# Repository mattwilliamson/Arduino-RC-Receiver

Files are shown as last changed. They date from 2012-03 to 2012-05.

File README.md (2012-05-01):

This is a simple project which will control a Radio Controlled vehicle via a serial interface, such as XBee or Bluetooth. The included `joystick.py` will use a joystick to transmit via XBee (or whatever serial interface you are using).

## Requirements:

* pyserial
* pygame

# TODO

**This project has been changed to send SUM PPM over Digital Pin 9 from the arduino to the aeroquad Digital 2 pin instead of one pin for each channel.** All of the diagrams below info pertains to the sketch names `serial_servo_rx`.

## Usage

* Upload the `serial_ppm_rx` sketch to your Arduino.
* Connect your servos to your Arduino per the below pinouts
* Run `python joystick.py`
* Use your joystick and watch the servos go!

I am using an XBee hooked up to an arduino plugged into my computer as the serial out interface and the other XBee is connected to my Arduino.

You can use whatever radio (including bluetooth) as long as your computer recognizes it as a serial port and the receiver spits out TTL on RX0 on your Arduino.

One example would be a standard bluetooth adapter on your computer and one of these [bluetooth ttl adapters](http://www.amazon.com/gp/product/B006T0Q8AQ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).

As for the joystick, I am using a [Saitek ST290](http://www.amazon.com/gp/product/B0000AW9RE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)
so you may need to change the code a little to match the buttons you want to perform which function.

Currently all buttons work as toggles.

## Caveats

* Set your XBees to 38400 baud. This was picked since it's safe to use with Series 1 XBee radios.

## Pinouts

This is as it relates to the `joystick.py` control file and it maps to the Saitek joystick mentioned above.

* Arduino Digital 2: Throttle
* Arduino Digital 3: Roll
* Arduino Digital 4: Pitch
* Arduino Digital 5: Yaw
* Arduino Digital 6: Aux1
* Arduino Digital 7: Aux2
* Arduino Digital 8: Aux3
* Arduino Digital 9: Aux4
* Arduino Digital 13: Status LED

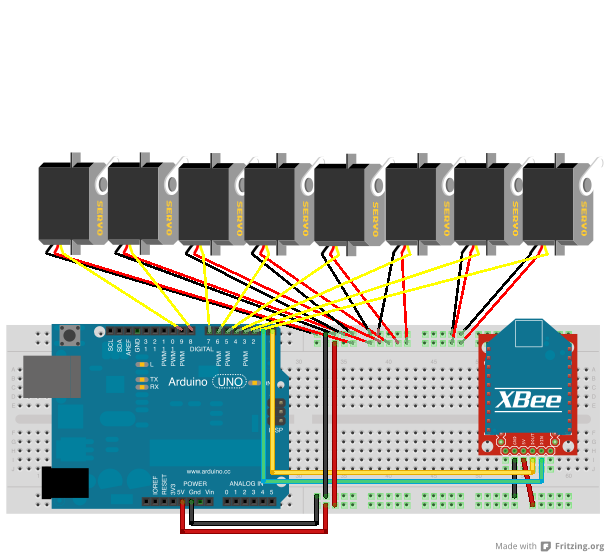
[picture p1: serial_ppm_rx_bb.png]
Schematic


Breadboard

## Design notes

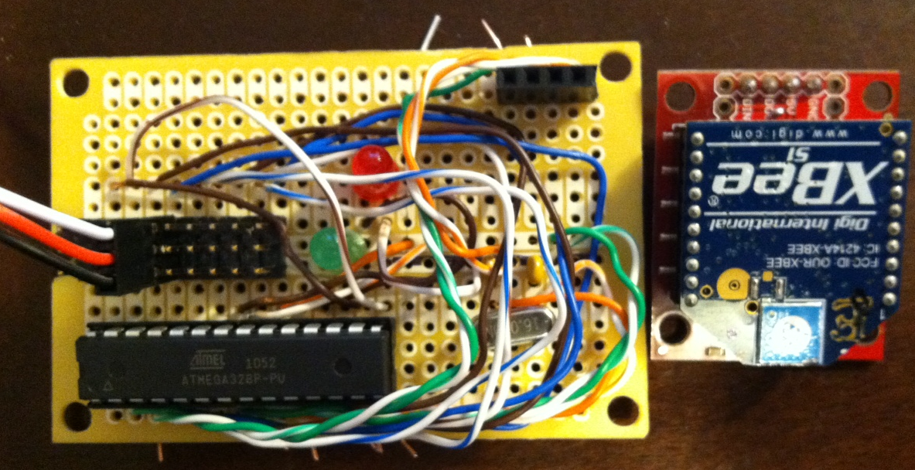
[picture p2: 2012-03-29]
receiver_board.png

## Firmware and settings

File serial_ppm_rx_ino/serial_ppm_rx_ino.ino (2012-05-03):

#include <TimerOne.h> 

#define CHANNELS 8

// Set these a little high since they are registering low on AQ
#define MIN_PULSE_TIME 1030   // 1000us
#define MAX_PULSE_TIME 1990   // 2000us
#define HALF_PULSE_TIME (MIN_PULSE_TIME + MAX_PULSE_TIME) / 2
#define SYNC_PULSE_TIME 3050  // 3000us

#define SERIAL_BAUD 38400

#define PIN_LED 13
#define PIN_PPM 9

#define RECEIVER_TIMEOUT 1500 // 1.5s
#define MIN_RECEIVER_VALUE 0
#define MAX_RECEIVER_VALUE 250

// For Aeroquad, this should disarm the quad when reception is lost
// TODO: Need to match AQ's channels
// YAXIS,ZAXIS,THROTTLE,XAXIS,AUX1,AUX2,0,0
const unsigned int defaultPulseWidths[CHANNELS] = {
  MIN_PULSE_TIME,      // Throttle
  HALF_PULSE_TIME,     // Roll
  HALF_PULSE_TIME,     // Pitch
  MIN_PULSE_TIME,      // Yaw
  
  MAX_PULSE_TIME,     // AUX1 (MODE in Aeroquad)
  MAX_PULSE_TIME,     // AUX2 (ALTITUDE in Aeroquad)
  MAX_PULSE_TIME,     // AUX3
  MAX_PULSE_TIME      // AUX4
};


// Inbound data is: [throttle, roll, pitch, yaw, aux1, aux2, aux3, aux4]
// AeroQuad expects: [XAXIS,YAXIS,THROTTLE,ZAXIS,MODE,AUX1,AUX2,AUX3]
// Make sure you define SERIAL_SUM_PPM_2 in AeroQuad!
const int channelMap[CHANNELS] = {1, 2, 0, 3, 4, 5, 6, 7};

unsigned int pulseWidths[CHANNELS];
byte buffer[CHANNELS];
int bytesReceived;
byte currentByte;
unsigned long lastReceived = 0;
boolean armed = false;

void setDefaultPulseWidths() {
  for (int i=0; i<CHANNELS; i++) {
    pulseWidths[i] = defaultPulseWidths[i];
  }
}

void setup() {
  pinMode(PIN_LED, OUTPUT);
  pinMode(PIN_PPM, OUTPUT);

  Serial.begin(38400);
  
  setDefaultPulseWidths();
  
  // Start timer with sync pulse
  Timer1.initialize(SYNC_PULSE_TIME);
  Timer1.attachInterrupt(isr_sendPulses);
  isr_sendPulses();
}

void loop() {
  handleSerial();
  checkArmed();
  checkLostReception();
} 

void handleSerial() {
  // Handle Serial Data
  if (Serial.available()) {
    lastReceived = millis();
    currentByte = Serial.read();

    if (currentByte == 254) {
      // Either packet is done, or we got corrupt data. Reset the packet
      bytesReceived = 0;
    } else {
      buffer[bytesReceived] = currentByte;
      bytesReceived++;
    }

    if (bytesReceived == CHANNELS) {
      bytesReceived = 0;
      armed = true;

      // Convert char (0-250) to pulse width (1000-2000)
      for (int i=0; i<CHANNELS; i++) {
        pulseWidths[i] = map(buffer[i], MIN_RECEIVER_VALUE, MAX_RECEIVER_VALUE, 
                                        MIN_PULSE_TIME, MAX_PULSE_TIME);
      }
    }
  }
}

void checkArmed() {
  if(!armed) {
    // Not Armed yet (no packets received) or lost reception, blink the LED
    // and set the dault positions
    setDefaultPulseWidths();
    
    digitalWrite(PIN_LED, HIGH);
    delay(300);
    
    digitalWrite(PIN_LED, LOW);
    delay(300);
  } else {
    digitalWrite(PIN_LED, HIGH);
  }
}

void checkLostReception() {
  // Check if we lost reception
  if(armed && lastReceived > 0 &&  millis() - lastReceived > RECEIVER_TIMEOUT) {
    armed = false;
    
    for(int i=0; i<5; i++) {
      digitalWrite(PIN_LED, HIGH);
      delay(100);
      digitalWrite(PIN_LED, LOW);
      delay(100);
    }
  }
}

// Sync pulse first
volatile int currentChannel = 0;

void isr_sendPulses() {
  digitalWrite(PIN_PPM, LOW);
  
  if (currentChannel == CHANNELS) {
    // After last channel
    Timer1.setPeriod(SYNC_PULSE_TIME);
    currentChannel = 0; // Will be 0 on next interrupt
  } else {
    Timer1.setPeriod(pulseWidths[channelMap[currentChannel]]);
    currentChannel++;
  }
  
  digitalWrite(PIN_PPM, HIGH);
}

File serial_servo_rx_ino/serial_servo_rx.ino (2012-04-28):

#include <Servo.h> 

#define SERVOS 8
#define PIN_LED 13
#define LED_TIME 1000
#define MIN_SERVO_POS 40
#define MAX_SERVO_POS 150
#define AUTO_DESCENT_ENABLED
#define AUTO_DESCENT_TIMEOUT 1500
#define AUTO_DESCENT_RATE 1 // Per 100ms

Servo servos[SERVOS];
int positions[SERVOS];
byte buffer[SERVOS];
int bytesReceived;
byte currentByte;
unsigned long lastReceived;
unsigned long lastLed;
boolean armed = false;

void setup() 
{ 
  pinMode(PIN_LED, OUTPUT); 
  Serial.begin(38400);
  bytesReceived = 0;
  lastReceived = 0;
  lastLed = 0;

  for(int i=0; i<SERVOS; i++) {
    positions[i] = MIN_SERVO_POS;
    servos[i].attach(1 + i);
    servos[i].write(MIN_SERVO_POS);
  }
} 


void loop() 
{
  if(lastLed && abs(millis() - lastReceived) > LED_TIME) {
    digitalWrite(PIN_LED, LOW);
    lastLed = 0;
  }

  if (Serial.available() > 0) {
    digitalWrite(PIN_LED, HIGH);
    lastReceived = millis();
    lastLed = lastReceived;
    currentByte = Serial.read();
    armed = true;

    if (currentByte == 254) {
      // Either packet is done, or we got corrupt data. Reset the packet
      bytesReceived = 0;
    }

    buffer[bytesReceived] = currentByte;
    bytesReceived++;

    if(bytesReceived == SERVOS) {
      bytesReceived = 0;

      // Send Servo Commands
      for(int i=0; i<SERVOS; i++) {
        int servoPos = map(buffer[i], 0, 250, MIN_SERVO_POS, MAX_SERVO_POS);
        servos[i].write(servoPos);
        positions[i] = servoPos;
      }
    }
  }

  if(!armed) {
    // Autodescent
#ifdef AUTO_DESCENT_ENABLED
    servos[2].write((MAX_SERVO_POS + MIN_SERVO_POS) / 2);
    positions[2] = (MAX_SERVO_POS + MIN_SERVO_POS) / 2;
    servos[3].write((MAX_SERVO_POS + MIN_SERVO_POS) / 2);
    positions[3] = (MAX_SERVO_POS + MIN_SERVO_POS) / 2;
    servos[4].write((MAX_SERVO_POS + MIN_SERVO_POS) / 2);
    positions[4] = (MAX_SERVO_POS + MIN_SERVO_POS) / 2;

    // Aux1
    servos[5].write(MAX_SERVO_POS);
    positions[5] = MAX_SERVO_POS;
#endif
    

    // Throttle
    int stepInterval = 100;

    while (positions[1] > MIN_SERVO_POS) {
      delay(stepInterval / 2);
      digitalWrite(PIN_LED, HIGH);

      positions[1] -= AUTO_DESCENT_RATE;
      positions[1] = positions[1] > MIN_SERVO_POS ? positions[1] : MIN_SERVO_POS;
      servos[1].write(positions[1]);

      delay(stepInterval / 2);
      digitalWrite(PIN_LED, LOW);
    }

    // Not Armed yet (no packets received), blink the LED
    digitalWrite(PIN_LED, HIGH);
    delay(500);
    digitalWrite(PIN_LED, LOW);
    delay(500);
  }

#ifdef AUTO_DESCENT_ENABLED
  unsigned long now = millis();

  if(lastReceived > 0 && lastReceived < now && (now - lastReceived) > AUTO_DESCENT_TIMEOUT) {
    armed = false;
  }
#endif
} 

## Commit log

2012-03-29 Added diagram
    [serial_ppm_rx.fzz]
2012-03-29 Added schematic to readme
2012-03-29 Updated schematic
    [serial_ppm_rx.fzz]
2012-03-29 Added actual board
2012-04-19 Transmitter works with quadcopter and even has autodescent in case of lost signal\!
    [nano_receiver.fzz]
2012-05-02 Added link to Arduino IDE
2012-05-02 Revert "Added link to Arduino IDE"
    This reverts commit 693ac97f6ae42f2efc38a6a0f0e206085000b226.
    [serial_ppm_rx_ino.ino]
